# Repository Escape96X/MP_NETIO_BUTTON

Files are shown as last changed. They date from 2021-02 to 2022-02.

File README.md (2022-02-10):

# Manual
## How to install on esp8266 with Netio ESP flasher
Best method is to use Visual studio code with plugin Platformio.  
1. Download 'Kód' folder of this repository
2. After installation of VS code and Platformio override esptool.py in platformio
	- Windows path: C:\Users\\**username**\\.platformio\packages\tool-esptoolpy\esptool.py
3. Connect
	- Rx to Tx
	- Tx to Rx
	- GND to GND
	- PROG to PIO0
	- <a href = 'https://github.com/jiricmi/MP_NETIO_BUTTON/issues/14#issuecomment-888953459'>3,3 V to 3,3 V (You have to solder that to R2)</a>
	- <a href = 'https://github.com/jiricmi/MP_NETIO_BUTTON/issues/14#issuecomment-888953459'>RST to ESPEN (solder to RST button)</a>
4. Upload with platformio

<h2>NETIO button tutorial</h2>
<h3>How to set it up</h3>
<ol>
<li>Turn it on with ON/OFF switch</li>
<li>Hold both buttons until red light blinks once.</li>
<li>Open WiFi manager and find <b>NETIO-BUTTON</b> network and search <b>192.168.4.1</b> in internet browser</li>
<li>Under WiFis find your WiFi and click on it after that enter your password</li>
<li>After connecting, copy IP address of the device, reconnect to your network and enter new IP to your browser</li>
</ol>
<h3>Connect to Netio socket</h3>
<ol>
<li>Select <b>Action list</b> on main screen</li>
<li>Click on button <b>add</b></li>
<li>Enter IP adress of Netio socket (only IP without http:// or /netio.json)</li>
<li>Enter JSON string</li>
<li>Choose which button should use this command and submit</li>
<li> You can delete each record in table by clicking on button <b>Delete</b>
<li> On main screen click on button <b>Deep sleep</b> to end <b>conf-mode</b>
</ol>

<h2>Basic info</h2>
<p>
This is prototype of NETIO button that allow you to control the NETIO socket.
It works on sending HTTP request method.
On the other side, this communication is handled by the socket via JSON API. Button is made with small consumption. Button is only up when user sends HTTP request or turns on conf-mode.
</p>
<h3>Device structure</h3>
<p>
Device has 2 buttons with S1 and S2 marks. They are used for <b>JSON configure</b>.
User can program those buttons via conf-mode. <br>
</p>
<h3>LED and buzzer signaling</h3>
<p>
Device has LED with green and red color.
Buzzer is connected with red color of LED.<br>
If <b>green light</b> is on, device is trying to connect to wlan or communicate with the socket. <br>
If <b>red light</b> blinks once for longer time, device entered or quited conf-mode.<br> 
If <b>red light</b> blinks 2x with buzzer signalization, connection to wlan failed. <br>
If <b>red light</b> blinks 3x with buzzer signalization, HTTP communication failed.
Probably IP address of the socket is invalid. <br>
If <b>red light</b> blinks 4x with buzzer signalization, device wasn't able to recognize input. Please hold the button little bit longer.
</p>
<h2>Conf-mode</h2>
<p>
For entering conf-mode, hold both buttons until light turn on for 400ms. After that connect to AP called <b>NETIO-BUTTON</b>. Open browser and search <b>192.168.4.1</b>.
</p>
<h3>WiFi selection</h3>
<p>
On main screen, user is able to connect device to any close-range network without security or with WES, WPA or WPA2-personal. For update WiFi list, click on <b>Scan</b> button. <br>
By clicking on button with your wanted network, you will be transfer to security page (only if network is secured). If password is checked, page will show you IP address of device selected by DHCP server in network. And now you are able to connect to conf-mode via your network and appropriate IP address.
</p>
<h3>IP address of the socket</h3>
<p>
User is able to set 10 IP addresses for each button. So one HTTP request will be send a maximum of 10 devices at once. You can add IP address via form where you also select with button should use this IP address. It is possible to delete each address.
</p>
<h3>JSON message</h3>
<p>
Behind button configure you can find feature to write JSON message to JSON API of socket. Current JSON is below the form.
</p>
<h3>Disable conf-mode button</h3>
<p>This button will put device to sleep. Holding both buttons during conf-mode has same effect.</p>
<h3>Factory reset button</h3>
<p>Deletes whole EEPROM.</p>

# Obsah
📦MP_NETIO_BUTTON  
 ┣ 📂kod - - **Finální program**  
 ┣ 📂dokumentace - **Dokumentace s latex soubory**  
 ┃ ┗ 📜document.pdf   
 ┣ 📂mereni - **Waveform a screenshoty**    
 ┃ ┣ 📂esp32  
 ┃ ┃ ┣ 📂operace  
 ┃ ┃ ┣ 📂ustalene_stavy  
 ┃ ┃ ┗ 📜vysledky_mereni_esp32.xlsx  
 ┃ ┗ 📂esp8266  
 ┃ ┃ ┣ 📂operace  
 ┃ ┃ ┣ 📂ustalene_stavy  
 ┃ ┃ ┗ 📜vysledky_mereni_esp8266.xlsx  
 ┣ 📂navrh_vzorku - **Eagle**    
 ┃ ┣ 📂esp32  
 ┃ ┗ 📂esp8266  
 ┣ 📜.gitignore  
 ┗ 📜README.md  
# Poděkování
*Chtěl bych poděkovat panu učiteli Ing. Břetislavu Bakalovi za odborné vedení práce
a cenné rady, které mi pomohly tuto práci zkompletovat. Rád bych také poděkoval technickému řediteli Ing. Břetislavu Bakalovi ml. společnosti NETIO products a.s. za cenné
rady, věcné připomínky a vstřícnost při konzultacích a vypracování maturitní práce*.
# Úvod maturitní práce
V této maturitní práci porovnám platformy ESP8266 a ESP32 z hlediska spotřeby a reakčního času v takových podmínkách, aby bylo možné určit platformu, která je vhodnější pro funkční vzorek ovladače zásuvek od společnosti NETIO Products a. s. Jelikož je cílem vytvořit co nejvíce úsporné zařízení, jak je jen možné, budu porovnávat jednotlivé ustálené stavy. Zařízení také musí být uživatelsky přívětivé, tzn. není ideální, když
uživatel musí čekat na reakci několik sekund.

Dále na každé platformě porovnám rychlost a spotřebu připojení k WiFi síti a následné odeslání HTTP requestu.
Po vybrání vhodné metody ustáleného stavu, vytvořím konfigurační rozhraní pro editaci nastavení sítě a HTTP requestu, do kterého se bude přistupovat přes access point zařízení ESP.  

Ve finále vytvořím dva funkční koncepty ovladačů pro každou platformu. Tento koncept
bude vycházet z předchozího měření a zjištění. Funkčním vzorkem bude možné ovládat,
buď dvě různé zásuvky, nebo jednu zásuvku z dvěma výstupy. V závěru práce zhodnotím,
zda je možné vytvořit plnohodnotný produkt, či nikoliv.

# Zadání maturitní práce

- V dokumentaci popište technologie NETIO, ESP8266 a ESP32 s ohledem na požadované funkce ovladače
- Navrhněte vhodné uživatelsky přívětivé rozhraní pro konfiguraci ovladače a jeho
připojení do WiFi sítě
- Realizujte požadované funkce na ovladač:
	- vstup na 2 nezávislá tlačítka pro standardní dvojitý přepínač/spínač dvou samostatných zásuvek jednoho zařízení NETIO, eliminace rychlých mačkání (nervózní uživatel)
	- nepodařený příkaz/přepnutí vypínače (nepodaří se odeslat příkaz http) je indikován bliknutím LED a pípnutím buzzeru. Kontroluje se odpověď http serveru (např. 200, 404 návratové hodnoty)
	- Zvolte vhodnou technologii výroby funkčních vzorků (nepájivé pole, DPS) a vyrobte jeden funkční vzorek na bázi ESP8266 a druhý na bázi ESP32 s možností měření odebíraného proudu
	- Určete vhodnou metodu měření dynamické spotřeby energie v čase (reakční doby) pro různé režimy připojení, způsobu komunikace a platformy procesoru:
		- ESP je vypnuto a vzbudí se nějakým externím obvodem přes enable/reset vstup po stisku tlačítka
		- ESP je v deep sleep módu - low power režimu a vzbudí se tlačítkem
 		- ESP je kontinuálně zapnuto
		- Kolik energie spotřebují uvedené režimy při napájení z baterie. Výsledky měření názorně porovnejte
	- Celou dokumentaci včetně výpisů zdrojového programu s komentářem veďte ve verzovacím systému Git a elektronicky doložte k tištěné podobě dokumentace
## Kritéria funkčnosti
- vyrobené vzorky ovladače (ESP8266 a ESP32) jsou funkční
- je vytvořeno uživatelské rozhraní pro konfiguraci ovladač
- bylo provedeno měření spotřeby a doby odezvy pro oba typy ovladače

## Výstupy
- srovnání platforem ESP32 a ESP8266 s ohledem na požadované funkce
- návrh požadovaných funkcí ovladače
- návrh variant ovladače s platformou ESP32 a ESP8266 ve formě ověření konceptu
- zdrojové kódy v repozitáři GIT (GitHub nebo GitLab)
- schéma zapojeni všech zkoušených variant v řešení
- srovnání spotřeby a reakční doby funkčních vzorků

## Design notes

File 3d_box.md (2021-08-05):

# 3D prited box
this box is supporting SMD in this repository. 

Box is [HERE](https://a360.co/3rSHOem). Password is "netio-button".

Box is printed on PRUSA MK3S nozzle 0.4 with PETG filament

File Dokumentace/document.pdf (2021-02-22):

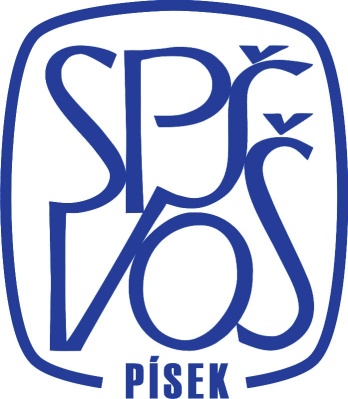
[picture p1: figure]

Střední průmyslová škola a Vyšší odborná škola, Písek, Karla Čapka 402, Písek

18-20-M/01 Informační technologie

# Maturitní práce

# Dálkové ovládání zásuvek NETIO

Téma číslo 12

autor:

Milan Jiříček, B4.I

vedoucí maturitní práce:

Ing. Břetislav Bakala

Písek 2020/2021

## Anotace

Maturitní práce se zaměřuje na porovnání platforem ESP8266 a ESP32. Cílem je vytvořit

ovladač pro ovládání zásuvek značky NETIO s webovou aplikací pro konfiguraci a zjistit,

která platforma je vhodná pro realizaci funkčního vzorku z hlediska spotřeby energie

a reakční doby.

## Annotation

The graduation thesis focuses on the comparison of the ESP8266 and ESP32 platforms.

The goal is to create a driver for controlling NETIO sockets with a web application

for configuration and to find out which platform is suitable for the implementation of

a functional sample in terms of energy consumption and response time.

Poděkování

Chtěl bych poděkovat panu učiteli Ing. Břetislavu Bakalovi za odborné vedení práce

a cenné rady, které mi pomohly tuto práci zkompletovat. Rád bych také poděkoval technic-

kému řediteli Ing. Břetislavu Bakalovi ml. společnosti NETIO products a.s. za cenné rady,

věcné připomínky a vstřícnost při konzultacích a vypracování maturitní práce. V neposlední řadě chci poděkovat Mgr. Haně Maříkové a Mgr. Vladimíře Špirhanzlové za pomoc

při gramatické a stylistické kontrole.

# Obsah

1 Úvod | 5
2 Teoretický úvod do problematiky | 6
3 Metodika postupu | 11
4 Měření spotřeby a času | 16

5 Vytvoření funkčních vzorků | 24
6 Závěr | 25
Přílohy | 27
A Příloha | 28

# Kapitola 1

# Úvod

# Kapitola 2

# Teoretický úvod do problematiky

## 2.1 Zásuvka NETIO

## 2.2 Platforma ESP

ESP jsou rodina mikročipů od společnosti Espressif Systems.

### 2.2.1 ESP8266

Historie

ESP8266 je levný mikročip, který umí využívat WiFi. První chip, který se dostal na světlo

světa byl v modulu ESP-01. Tento modul dokázal připojit se na WiFi síť a provádět

jednoduché TCP/IP spojení. Získal si velkou oblibu díky nízké ceně. Jsou vhodné pro IoT

jako například automatizace, zabezpečení, chytré domy atd.

Specifikace

Pro tuto maturitní práci bude použit modul WT8266-S1, který je vytvořen společností

Wireless-Tag, protože tento modul je používán ve společnosti NETIO products a. s. Je

založen na mikročipu ESP8266.

ESP8266 integruje vylepšenou verzi procesoru L106 Diamond series 32-bit vytvořený

firmou Tensilica s podporou frekvencí 80 MHz a 160 MHz a RTOS¹
. K dispozici je 36 KB

RAM a 16 Mbit Flash paměti. Intergrovaný v systému je také 10 bitový analog-digitální

převodník. Modul podporuje standard IEEE802.11 b/g/n 2 a sadu protokolů TCP/IP.

1Operační systém v realném čase
2Standard pro lokální bezdrátové sítě

WiFi 2,4 GHz umožňuje WPA/WPA2 3 , rychlost až 72,2 Mbps a ke komunikaci využívá

anténu PCB. Zařízení má 16 GPIO pinů⁴
(viz. obr. 2.1) z toho jsou některé piny využívány

na specifické činnosti. Např. pokud při bootu ESP8266 přivedeme GROUND na GPIO

0, zařízení se přepne do UART⁵ módu a je možné nahrát do flash paměti program. Další

informace jsou na obrázku 2.2.

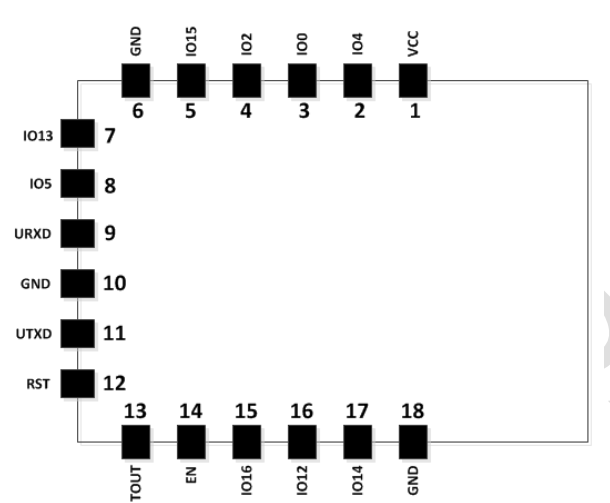
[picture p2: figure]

Obrázek 2.1: ESP8266 pinout: Literatura [1]

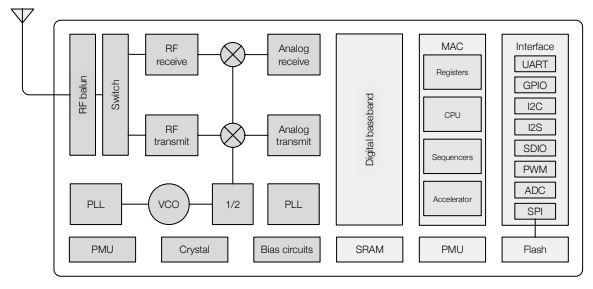
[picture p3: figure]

Obrázek 2.2: ESP8266 blokový diagram funkcí: Literatura [2]

### 2.2.2 ESP32

ESP32 je mladší model z řady ESP, který byl vydán v roce 2016. Tento mikročip má

integrované WiFi i Bluetooth. Série ESP32 obsahuje mikroprocesor Tensilica Xtensa LX6

3Chráněný přístup k WiFi
4Vstupně výstupní pin
5Univerzální asynchronní přijmač, vysílač v dvou jádrové či jednojádrové verzi, který může operovat na 160 MHz nebo 240 MHz.

SRAM je zde byla zvetšena na 520 kB. WiFi může dosáhnout rychlosti až 150 Mbps

společně se zabezpečením WPA/WPA2. Kromě IPv4 je možnost použít i IPv6. ESP32

integruje 12 bitový analog-digitální převodník. Oproti ESP8266 je do tohoto modelu za-

budován senzor teploty. ESP32 disponuje 36 GPIO piny. Další funkce jsou na obrázku 2.3.

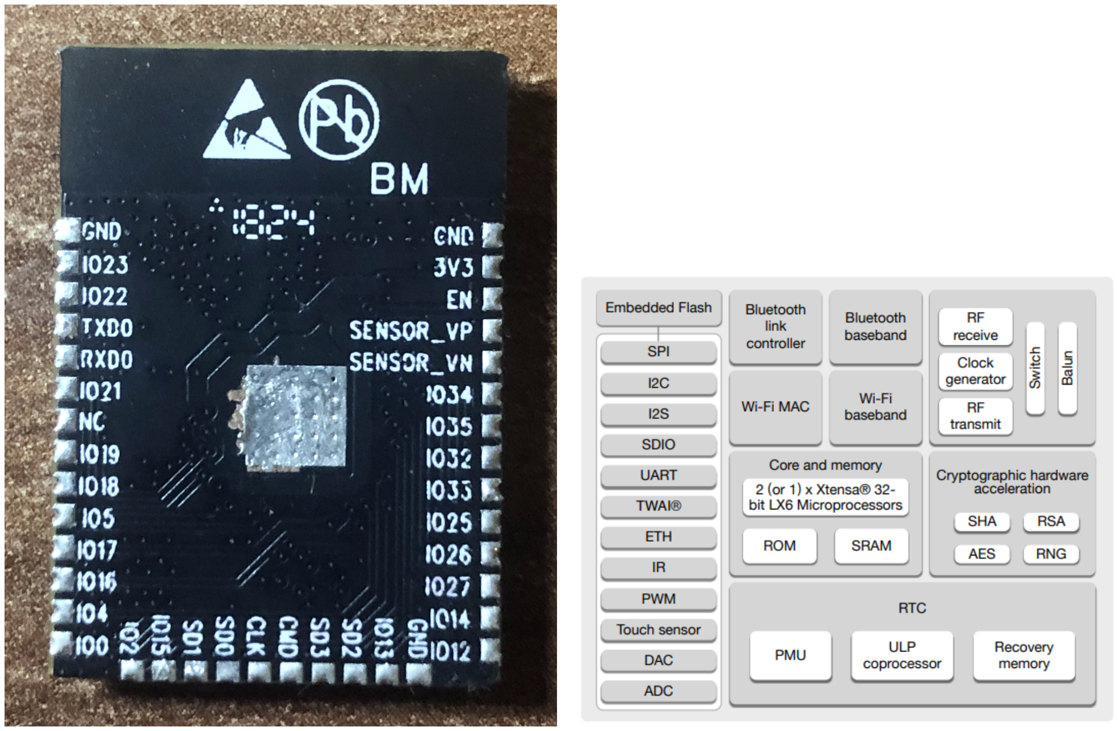
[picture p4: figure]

(a) pinout | (b) blokový diagram: Literatura [3]

Obrázek 2.3: ESP32 pinout a blokový diagram

### 2.2.3 Deep sleep

Platforma ESP lze také uvést do úsporného režimu. Jednoduše to znamená vypnutí ne-

důležitých částí pro ustálený stav. ESP8266 celkově nabízí 3 druhy úsporných režimů.

Modem, light a deep. Pro moji maturitní práci použiji deep sleep, který je nejúsporněj-

ších. Kromě RTC⁶
se vše vypne, včetně CPU či WiFi. V tomto režimu je také možné

uchovat data v tzv. RTC paměti, která jsou dostupná i po obnovení. Průměrná spotřeba

je 20 µA a je vhodný pro jakýkoliv projekt na akumulátor či baterii.

Probuzení ESP8266 probíhá, buď po nastaveném čase, kde je nutné připojit pin GPIO

6Hodiny realného času

### 16 tzv. wake-up pin na RESET (viz. obr. 2.4a), ten po uplynutí nastaveného času se na

krátkou dobu přepne z log. 1 na log. 0 a vyresetuje ESP8266, a nebo můžeme na RESET

přivést krátce tlačítkem logickou nulu a obnovíme ESP hardwarově (viz. obr. 2.4b).

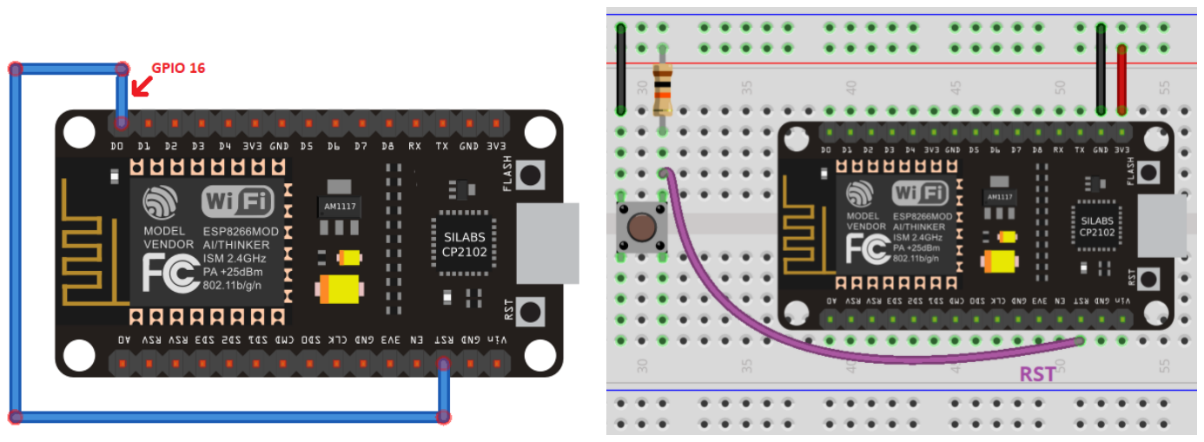
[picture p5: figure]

(a) Sotwarově po daném čase | (b) Hardwarově

Obrázek 2.4: ESP8266 probuzení z deep sleep po daném čase: Literatura [4]

Jelikož ESP32 je novější model, deep sleep se liší v používání. ESP32 neprobouzíme přes

RESET pin protože se ani na mikročipu ani nenachází. Pokud chceme ESP probudit po

určitém čase, nastavíme to pouze v programu a nemusíme žádné piny propojovat. V situ-

aci hardwarového probuzení je nutné definovat pin probuzení a při jaké logické hodnotě

se má probudit. Tento pin musí být tzv. RTC_GPIO⁷

## 2.3 LDLN030

LDLN030 je napěťový regulátor, který pracuje se vstupním napětím od 1,6 V do 5,5 V.

Výstupní napětí dokáže stabilizovat na 3,3 V a pokud napětí klesne pod 3 V, odpojí

zařízení napojené na výstupu. Tato součástka má časté použití v mobilních telefonech,

HDD a SSD discích a ostatních rařízeních napájené baterií.

Regulátor má celkem 5 pinů, a to vstup, výstup, GROUND, enable pin a Power Good.

Enable pin rozhoduje zda součástka funguje či nikoliv, pokud je přivedena na zem, výstup

je 0 V. Power Good je pin, který může informovat například základní desku během POST⁸ ,

že napájení je v pořádku a může pokračovat v činnosti.

7Pin, který je v činnosti i během spánku ESP
8Power On Self Test

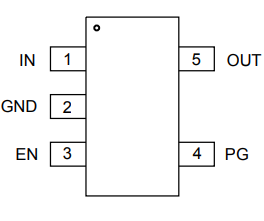
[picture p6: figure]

Obrázek 2.5: LDLN030 Pinout: Literatura [5]

# Kapitola 3

# Metodika postupu

## 3.1 Tvorba měřecího vzorku

Pro měření jednotlivých scénářů jsem si vytvořil vzorek, který byl určen pouze na měření.

Cílem bylo vytvořit vzorek jednoduše modifikovatelný, proto jsem zvolil pájivé pole na

základní část.

Na pájivém poli jsem napájel testovanou ESP platformu společně s přívodem, který byl

5 V. ESP má operační napětí 3,3 V, proto bylo nutné přidat stabilizator LDLN030,

který napětí stabilizoval na operačním napětí. Stabilizátor byl zapojen dle doporučeného

diagramu v datasheetu.

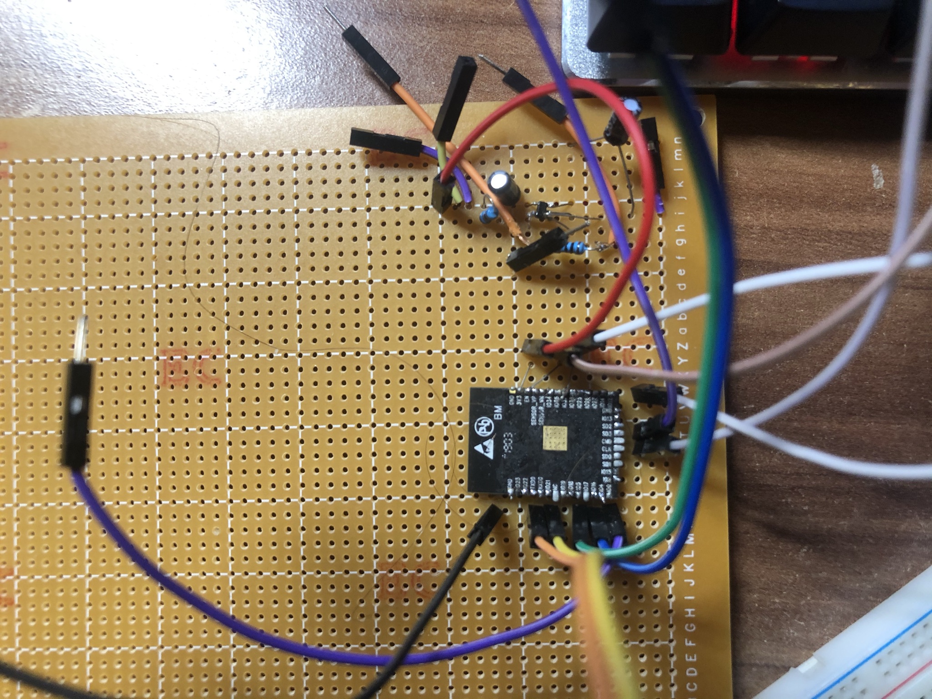
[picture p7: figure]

Obrázek 3.1: Vzorek pro měření na pajivém poli

Dále k potřebným GPIO pinům jsem napájel vodiče pro pozdější manipulaci. Pro další

specifická zapojení, jako např. tlačítko, jsem použil nepájivé pole, které jsem vždy připojil

specificky pro dané měření.

## 3.2 Měření připojení k WiFi a odeslání HTTP requestu

Cílem měření je zjistění rychlostí a spotřeby připojení různými způsoby k přístupo-

vému bodu a následné porovnání případů. Do měření je také započítáné odesílání HTTP requestu zásuvce. Jsou vytvořeny celkem 4 případy akcí:

- statická IP adresa - Zařízení dostane IP adresu, masku a bránu staticky sta-

ticky nakonfigurovanou. Na access pointu bude vyplé DHCP a komunikace nebude

zabezpečena.

- dynamická IP adresa - Bude využit DHCP protokol, kde zařízení požádá DHCP

server o IP adresu, kterou mu access point přidělí společně s bránou, maskou a s ča-

sem, kdy tato adresa platí. Při měření nebude přístupový bod zabezpečen.

- Zabezpečené připojení - Připojení na access point bude šifrované pomocí WPA2 -

PSK. DHCP server bude zapnut. Toto je simulace klasického uživatelského použí-

vání.

- Odeslání HTTP requestu - Zařízení je připojené k WiFi. Odešle zprávu zásuvce

a pokud dostane zpětnou vazbu od zásuvky, ukončí se činnost.

Ve všech scénářích bude měřeno zařízením ANALOG DISCOVERY 2 od Digilent.

Frekvence procesoru je 160 MHz a AP je vzdálen 3,5 m od zásuvky a funkčního vzorku

ovladače.

### 3.2.1 Spotřeba

Měřen bude úbytek napětí na bočníku¹ o velikosti určené u měření. V programu k mě-

řícímu zařízení je možné stejně jako na osciloskopu vytvořit graf naměřených hodnot v

dané vzorkovací frekvenci. Hodnoty napětí bude převedeno na hodnoty el. proudu pomocí

Ohmova zákona I =

U
R

. Amplitudy el. proudu budou sečteny a vyděleny počtem vzorků

[DOPLNIT VZOREC]. Tato operace nám poskytne zjištění průměrného el. proudu ve

scénáři. Spotřebu již vypočítáme dle:

E = U × I ×

t
3600

Čas t v sekundách je možné zjistit v následující kapitole.

1nízkoohmový rezistor

### 3.2.2 Reakční čas

Z naměřeného případu bude vyjmuta klidová část a rozdíl mezi posledním a prvním

vzorkem je poté reakční čas. V případě HTTP requestu nebude počítána část konfigurace

WiFi. Společně s měřením byl na serial monitor odesílány zprávy, kde se program

nachází. Poté se vyjmula část, která dle serial monitoru nepatří do scénáře.

## 3.3 Ustálené stavy

Pro ustálené stavy byly navrhnuty jednoduché programy pro co nejlepší porovnání. Ustá-

lený stav je stav, kdy zařízení čeká na uživatelský podnět jako např. stisknutí tlačítka.

Ideální ustálený stav musí splňovat:

1. nejkratší možnou reační dobu
2. nejnižší možnou spotřebu pro co nejdelší výdrž baterií

Reakční doba musí být v rámci uživatelské přívětivosti tzn. probuzení z tohoto stavu

nesmí trvat více jak 1,5 s. Zároveň se zařízení nesmí vypnout zdůvodu vybité baterie za

krátkou dobu. Porovnání proběhne mezi třemi scénáři, které mají jiné vlastnosti. Vybrány

byly následující:

- Kontinuální režim - V tomto stanu není žádná funkce ESP vypnuta.
- Deep sleep - ESP vypne vše až na RTC (kapitola viz. 2.2.3 na straně 8).
- Enable button - ESP je vypnuto pomocí přivedené GROUND na pin ENABLE.

### 3.3.1 Spotřeba

Cílem měření je nalézt stav s nejmenší spotřebou energie, jelikož finální prvek bude na-

pájen z baterií je důležité co nejdelší výdrž. Programy, které byly napsány pro měření:

- Kontinuální režim - Zařízení má nastavený určitý GPIO na tlačítko a monitoruje

zda bylo zmáčknuto. ESP také má otevřenou sériovou komunikaci.

- Deep sleep - Program zajišťuje probuzení ESP každých 5 s a odesílání zprávy na

serial monitoring.

- Enable button - Pro měření této situace není třeba specifický program

Pro měření bude použit ANALOG DISCOVERY s jeho funkcí osciloskopu. Na napá-

jení bude přidán bočník o velikosti 0,7 Ω, 10,5 Ω nebo 4,7 Ω

2
. Pomocí Ohmova zákona

I =

U
R

je možné zjistit el. proud. Příkon, který bude porovnán vypočítáme dle vztahu:

P = U × I

OBRÁZKY ZAPOJENÍ

### 3.3.2 Probuzení z ustálených časů

Ovladač, který je již připojen k WiFi, po stisknutí tlačítka odešle HTTP request zásuvce,

která zareaguje přepnutím stavu a odesláním zprávy zpět ovladači zda se povedlo či

nikoliv.

Reakční doba byla změřena pomocí kamery. K tlačítku jsem připojil LED, místnost jsem

izoloval od světla a zmáčknutí tlačítka a reakci zásuvky jsem natočil ve zpomaleném

režimu s 240 snímky za sekundu. Pro upravení videa jsem použil trial verzi programu

Sony Vegas (viz. obr. 3.2). Našel jsem rozsvícení LED tlačítka a rozsvícení LED zásuvky

ve videu a ustřihl jsem tento úsek od zbytku videa. Program poskytuje zobrazení počtu

snímku daného úseku. Reakční čas je následovně možný zjistit pomocí:

t =

Počet snímků úseku
Počet snímků za sekundu

2Je nutné zvolit takový odpor, aby byl úbytek napětí měřitelný.

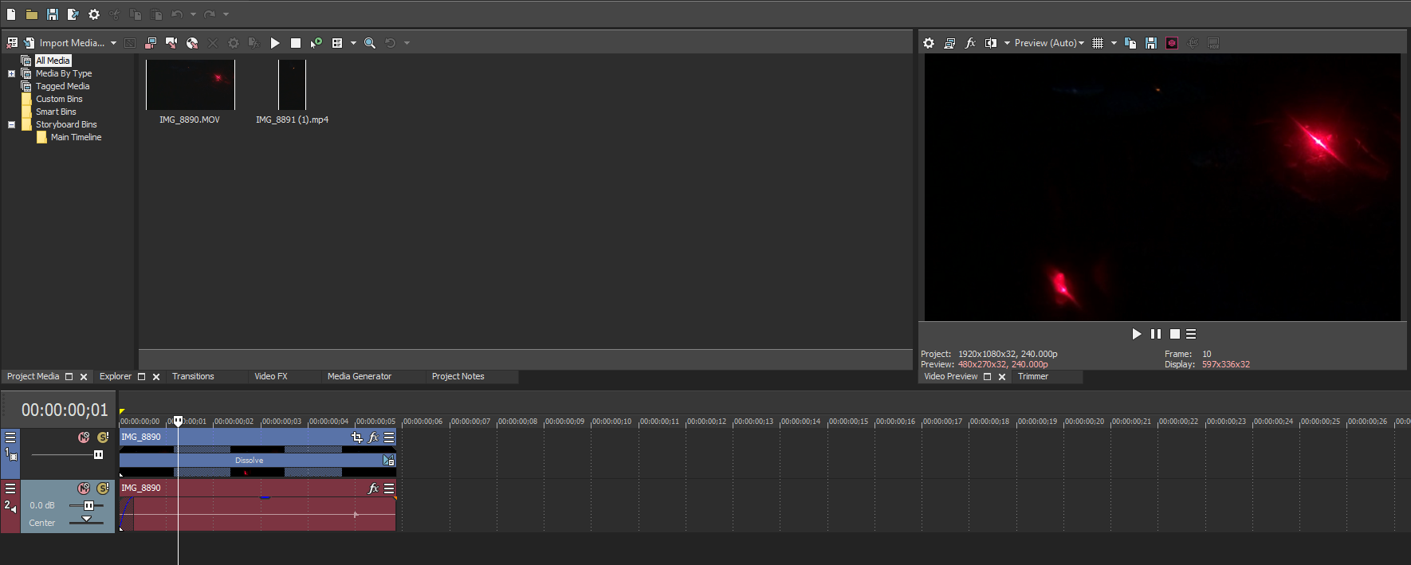
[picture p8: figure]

Obrázek 3.2: Ukázka postupu pro měření reakčních časů

# Kapitola 4

# Měření spotřeby a času

Všechny výpočty jsou k nalezení v adresáři "Měření"v souborech excel společně s použi-

tými programy a naměřenými hodnotami v grafech.

## 4.1 ESP8266

### 4.1.1 Spotřeba a reakční doba ustálených stavů

Spotřeba

Spotřeba jednotlivých scénářů je měřena dle metodiky 3.3.1 na straně 13. Bočník pro

měření úbytku napětí byl o velikosti 4,7 Ω.

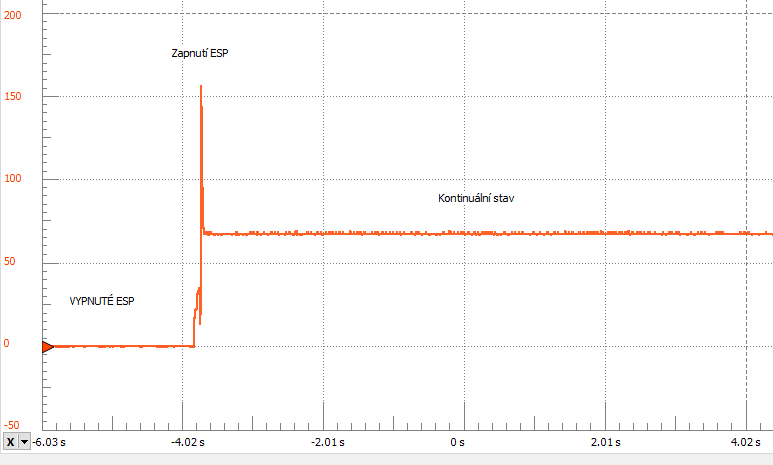
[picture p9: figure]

Obrázek 4.1: ESP8266 graf kontinuálního ustáleného stavu

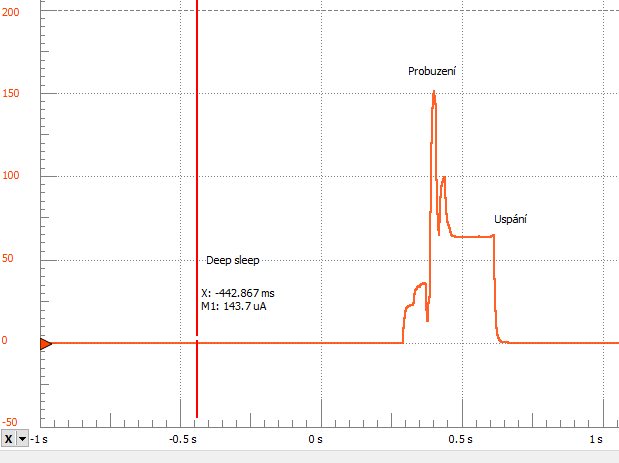
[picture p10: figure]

Obrázek 4.2: ESP8266 graf deep sleep ustáleného stavu

Situace enable button nebyla možná změřit zařízením ANALOG DISCOVERY 2

ani na bočníku o velikosti 0,7 Ω kvůli velice nízkému úbytku napětí, který se v datasheetu

WT8266 pohybuje v jednotkách µA. V tomto případě pro výpočty je použita hodnota,

kterou určil výrobce v datasheetu.

Tabulka 4.1: ESP8266 porovnání spotřeby ustálených stavů

Ustálený stav | U(V ) I(A) P(W)
Kontinuální Deep sleep Enable button | 3, 3 67, 66 × 10⁻³ 223, 3 × 10⁻³ 3, 3 138, 20 × 10⁻⁶ 460, 0 × 10⁻⁶ 3, 3 3, 00 × 10⁻⁶ 9, 9 × 10⁻⁶

Dle tabulky 4.1 je možné vidět jednotlivé situace. Největším příkonem disponuje konti-

nuální ustálený stav z důvodu běžícího programu na kontrolu interakce. Nejmenší spotřeba

je naopak vypnuté ESP přes enable pin.

Tabulka 4.2: ESP8266 porovnání reakčního času ustálených stavů

Ustálený stav | t(ms)
Kontinuální Deep sleep Enable button | 196 983 3 208

Reakční čas

Reakční čas byl měřen dle metodiky 3.3.2 na straně 14. Nejrychlejší ustálený stav je

kontinuální, kvůli připravenosti na interakci viz. tabulka 4.3. Nejdéle trvá vypnuté ESP,

protože je nutné ESP zapnout, nastavit konfiguraci a připojit na WiFi, zatím co zapnuté

ESP je již připraveno.

Porovnání

Pro porovnání spotřeb budeme předpokládat, že zařízení je napájeno 3× NiZn akumulá-

torem typu AA, které společně mají kapacitu 3750 mAh, což je možné prevést na energii

vztahem E = Uaku × kapacita. a dále vztahem¹
tp =

Ebat
P

zjistit provozní čas (viz. tabulka

4.3). Zařízení není schopno dosáhnout této výdrže protože pokud napětí klesne pod 3 V,

stabilizátor napájení odpojí.

Tabulka 4.3: ESP8266 porovnání ustálených stavů

Ustálený stav | P[W] tp[h] t[ms]
Kontinuální Deep sleep Enable button | 223, 3 × 10⁻³ 75,6 196 460, 0 × 10⁻⁶ 36 993,1 983 9, 9 × 10⁻⁶ 1 704 545,0 3 208

Kontinuální stav, zatímco má výdrž v rámci několika dní, reakční čas trvá necelých

200 ms. Enable button situace naprosto opačná. Reakční čas je pro uživatele dlouhý, ale

výdrž v tomto stavu bez interakce by se pohybovala v letech. Dobrý kompromis je situace

deep sleep, kdy zařízení reagovalo vždy do jedné sekundy a teoretická výdrž je v jednot-

kách let.

1
tp - provoz v ustáleném režimu, Ebat - energie 3× AA akumulátorů

### 4.1.2 Připojení k WiFi a odeslání HTTP requestu

Měření proběhlo dle metodiky 3.2 na straně 11 na bočníku 0,7 Ω.

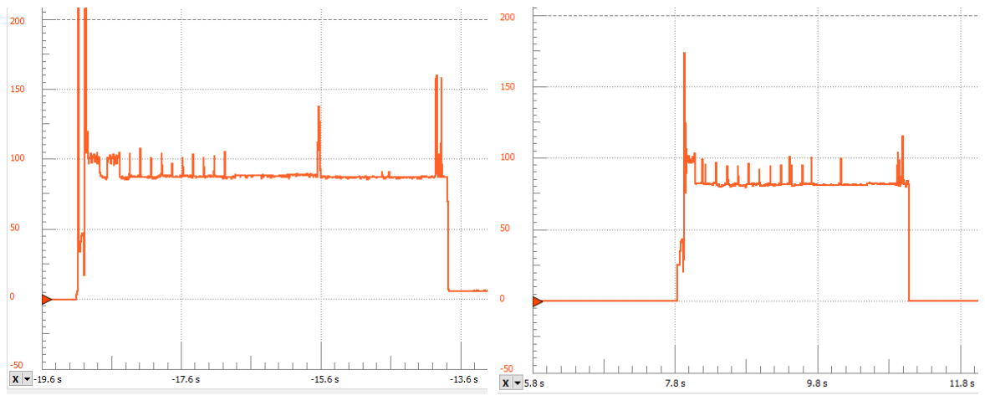
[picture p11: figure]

(a) Dynamická IP | (b) Statická IP

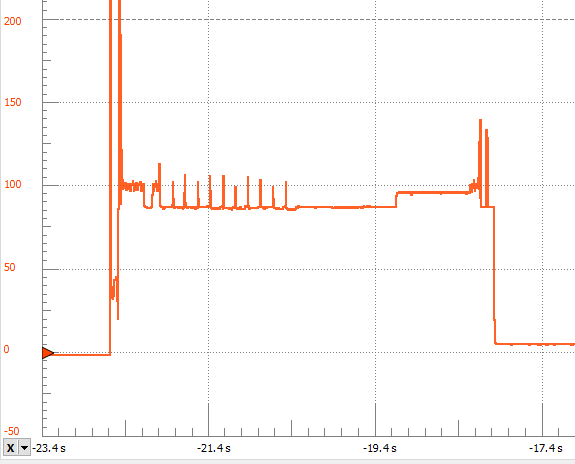
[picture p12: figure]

(c) Zabezpečené, dynamická IP

Obrázek 4.3: ESP8266 grafy WiFi situací

Z tabulky 4.7 je možné vidět, že příkon P je téměř totožný v každé operaci. Nej-

větší rozdíl, který ovlivňuje spotřebu, je čas, za který se úkon vykoná. Jelikož připojení

pomocí statické IP adresy trvalo nejkratší dobu, má také nejmenší spotřebu ener-

gie. Samotná komunikace HTTP má nejnižší spotřebu ze všech definovaných operací a

jeden cyklus operace spotřebuje zanedbatelné množství energie.

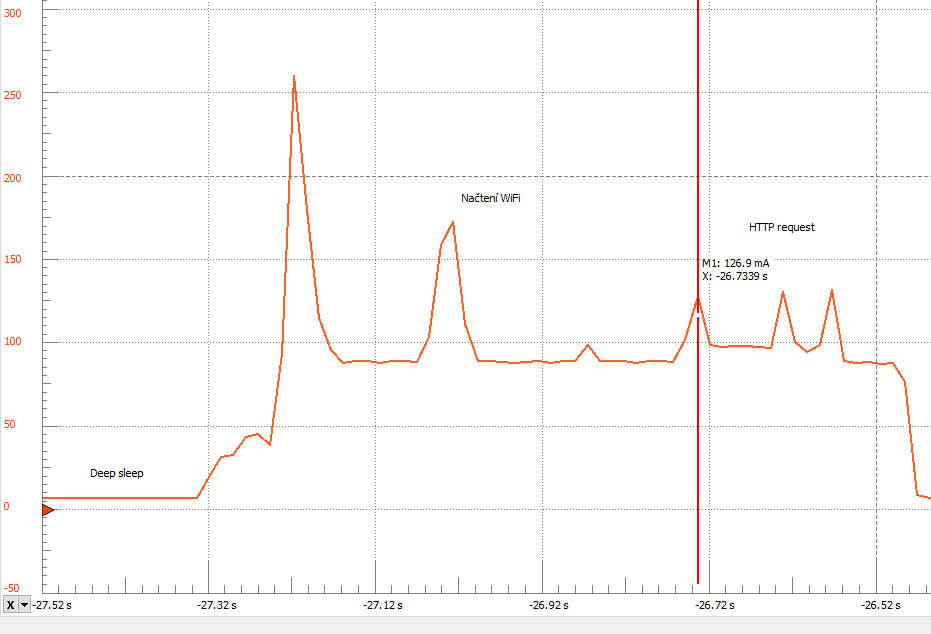
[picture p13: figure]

Obrázek 4.4: ESP8266 graf HTTP requestu

Tabulka 4.4: ESP8266 Spotřeba operací

Operace | U(V) I[mA] t[ms] P[mW] | E[µW h]
Dynamické připojení Statické připojení Zabezpečené připojení HTTP komunikace | 3,3 89,5 5 300 295 3,3 83,0 3 143 274 3,3 90,9 4 606 300 3,3 76,7 483 253 | 435 239 383 34

## 4.2 ESP32

### 4.2.1 Spotřeba a reakční doba ustálených stavů

Spotřeba

Spotřeba jednotlivých scénářů je měřena dle metodiky 3.3.1 na straně 13. Bočník pro

měření úbytku napětí byl o velikosti 10,5 Ω.

Ustálený stav enable pin nebyl naměřen zařízením Analog Discovery 2 z důvodu velmi

nízkému úbytku napětí na bočníku. K porovnání bude použita hodnota z datasheetu.

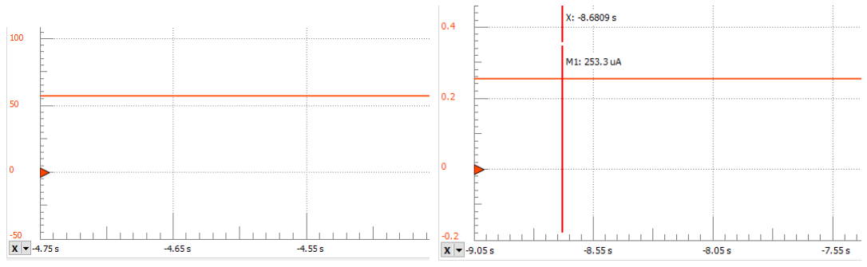
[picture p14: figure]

(a) Kontinuální | (b) Deep sleep

Obrázek 4.5: ESP32 grafy ustálených stavů

Tabulka 4.5: ESP32 porovnání spotřeby ustálených stavů

Ustálený stav | U[V ] I[A] P[W]
Kontinuální Deep sleep Enable button | 3, 3 57, 39 × 10⁻³ 189, 4 × 10⁻³ 3, 3 253, 39 × 10⁻⁶ 838, 0 × 10⁻⁶ 3, 3 1, 00 × 10⁻⁶ 3, 3 × 10⁻⁶

Reakční čas

Získání reakčních časů jednotlivých možností zapojení ESP32 proběhlo způsobem dle 3.3.1

na straně 13. Tabulka 4.6 ukazuje, že nejdéle trval ustálený režim v podobě vypnutého

ESP32 přes enable pin a nejkratší dobu trval kontinuální ustálený stav. Kompromis mezi

těmito dvěma stavy byl deep sleep ustálený stav, který se pohyboval okolo sekundy.

Tabulka 4.6: ESP32 porovnání reakčního času jednotlivých situací

Ustálený stav | t[ms]
Kontinuální Enable button Deep sleep | 188 2 333 1 071

### 4.2.2 Připojení k WiFi a odeslání HTTP requestu

Měření proběhlo podle metodiky 3.2 na straně 11.

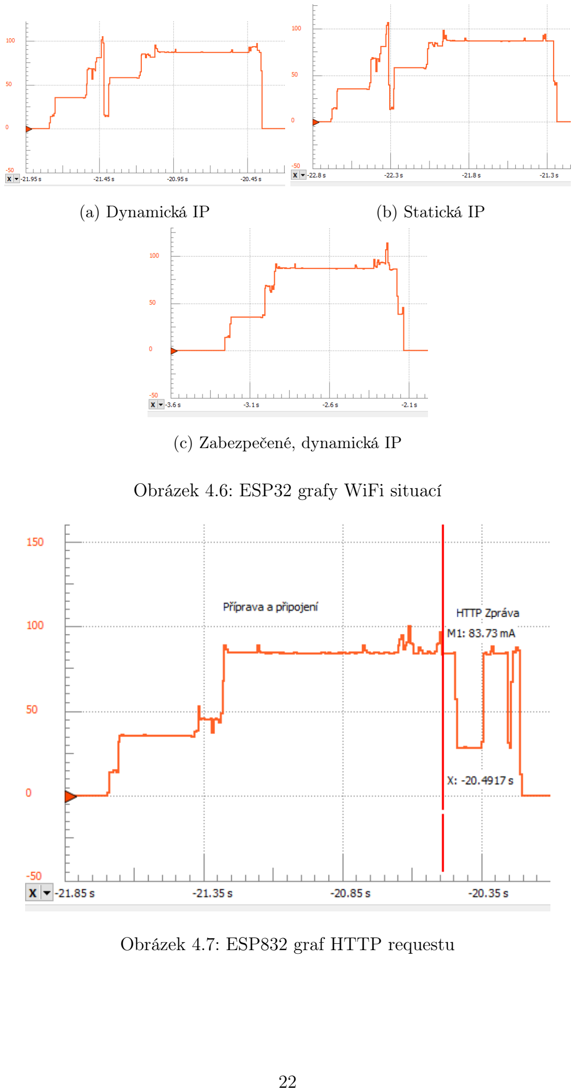
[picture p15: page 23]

(a) Dynamická IP | (b) Statická IP
(c) Zabezpečené, dynamická IP

Obrázek 4.6: ESP32 grafy WiFi situací

Obrázek 4.7: ESP832 graf HTTP requestu

Tabulka 4.7: ESP8266 Spotřeba operací

Operace | U[V] I[mA] t[ms] P[mW] | E[µW h]
Dynamické připojení Statické připojení Zabezpečené připojení HTTP komunikace | 3,3 72,0 1 406 238 3,3 69,2 1 400 228 3,3 74,7 1 081 246 3,3 62,6 281 207 | 92 88 74 16

## 4.3 Porovnání získaných výsledků

### 4.3.1 Ustálené stavy

Z tabulky 4.8 je možné vidět jak si platformy vedly proti sobě.

Pokud ovladač neustále běží s připojenou WiFi čas reakce je velmi rychlý a v obou případech uživatel nepostřehne prodlevu mezi aktivací ovladače a sepnutí relé v zásuvce. Časy

mezi platformami se liší minimálně a rozdíl se pohybuje v rámci milisekund, přesto je

ESP32 lehce rychlejší.

Zapnutí vypnutého ESP, následné načtení a připojení k WiFi je nejdelší ze všech scénářů,

který trvá několik sekund. Pro uživatele je velice pomalé a v realném produktu dle mého

názoru zcela nepoužitelné. I přesto je ESP32 je mnohem rychlejší a to zhruba o 1 s.

Deep sleep je alternativa mezi kontinuálním a vypnutým stavem. ESP totiž vypne vetšinu

svých částí. Díky tomu je schopno relativně rychle zareagovat na budící signál. Reakce

obou ovladačů je cirka 1 s. Zde vede ESP8266, které je zhruba o 100 ms rychlejší. Je to

zdůvodu komplikovanější struktuře ESP32.

Tabulka 4.8: Porovnání reakčních časů ústálených stavů platforem

Ustálený stav | ESP8266 ESP32 [ms] [ms]
Kontinuální Enable Deep sleep | 196 188 3 208 2 333 983 1 071

# Kapitola 5

# Vytvoření funkčních vzorků

## 5.1 Tvorba uživatelského rozhraní

# Kapitola 6

# Závěr

# Seznam tabulek

4.1 ESP8266 porovnání spotřeby ustálených stavů | 17
4.2 ESP8266 porovnání reakčního času ustálených stavů | 18
4.3 ESP8266 porovnání ustálených stavů | 18
4.4 ESP8266 Spotřeba operací | 20
4.5 ESP32 porovnání spotřeby ustálených stavů | 21
4.6 ESP32 porovnání reakčního času jednotlivých situací | 21
4.7 ESP8266 Spotřeba operací | 23
4.8 Porovnání reakčních časů ústálených stavů platforem | 23

# Seznam obrázků

2.1 ESP8266 pinout: Literatura [1] | | 7
2.2 ESP8266 blokový diagram funkcí: Literatura [2] | | 7
2.3 ESP32 pinout a blokový diagram | | 8
2.4 ESP8266 probuzení z deep sleep po daném čase: Literatura [4] | | 9
2.5 LDLN030 Pinout: Literatura [5] | 10
3.1 Vzorek pro měření na pajivém poli | 11
3.2 Ukázka postupu pro měření reakčních časů | 15
4.1 ESP8266 graf kontinuálního ustáleného stavu | 16
4.2 ESP8266 graf deep sleep ustáleného stavu | 17
4.3 ESP8266 grafy WiFi situací | 19
4.4 ESP8266 graf HTTP requestu | 20
4.5 ESP32 grafy ustálených stavů | 21
4.6 ESP32 grafy WiFi situací | 22
4.7 ESP832 graf HTTP requestu | 22

# Příloha A

# Příloha

# Literatura

[1] WT8266. | Wireless-Tag | Technology | Co.,Limited | [Online]. | Ir-
vine | (C): | Wireless-Tag, | 2021 | [cit.2021–02–22]. | Dostupné | z:

https://www.tme.com/Document/12266bdd8a30eeb152305461b089a151/WT8266-

S1.pdf

[2] ESP8266. | Espressif | Systems | [Online]. | Shangai, | Čína:
Espressif | Systems, | 2020 | [cit.2021–02–22]. | Dostupné | z:

https://www.espressif.com/sites/default/files/documentation/0a-

esp8266ex_datasheet_en.pdf

[3] ESP32. | Espressif | Systems | [Online]. | Shangai, | Čína:
Espressif | Systems, | 2020 | [cit.2021–02–22]. | Dostupné | z:

https://www.espressif.com/sites/default/files/documentation/esp32_datasheet_en.pdf

[4] ESP8266 | deep | sleep. | Random Nerd Tutorials [Online]. | Porto, Por-
tugalsko: RandomNerdTutorials.com, 2019 | [cit.2021–02–22]. | Dostupné z:

https://randomnerdtutorials.com/esp8266-deep-sleep-with-arduino-ide/

[5] DHCP protokol. | In: Wikipedia: the free encyclopedia [Online]. | San Fran-
cisco (CA): Wikimedia Foundation, | 2021 | [cit.2021–02–22]. | Dostupné z:

https://en.wikipedia.org/wiki_Dynamic_Host_Configuration_Protocol

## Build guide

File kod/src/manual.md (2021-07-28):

<html>
<head>
<style>
        body {
            font-family: "Helvetica",serif;

        }
    )
</style>
</head>
<body>
<h1>NETIO button tutorial</h1>
<h2>How to set it up</h2>
<ol>
<li>Turn it on with ON/OFF switch</li>
<li>Hold both buttons until red light blinks once.</li>
<li>Open WiFi manager and find <b>NETIO-BUTTON</b> network and search <b>192.168.4.1</b> in internet browser</li>
<li>Under WiFis find your WiFi and click on it after that enter your password</li>
<li>After connecting, copy IP address of the device, reconnect to your network and enter new IP to your browser</li>
</ol>
<h2>Connect to Netio socket</h2>
<ol>
<li>Select <b>Devices</b> on main screen</li>
<li>Click on button <b>add</b></li>
<li>Enter IP adress of Netio socket (only IP without http:// or /netio.json)
<li>Enter JSON string</li>
<li>Choose which button should use this command and submit</li>
<li> You can delete each record in table by clicking on button <b>Delete</b>
<li> On main screen click on button <b>Deep sleep</b> to end <b>conf-mode</b>
</ol>

<h2>Basic info</h2>
<p>
This is prototype of NETIO button that allow you to control the NETIO socket.
It works on sending HTTP request method.
On the other side, this communication is handled by the socket via JSON API. Button is made with small consumption. Button is only up when user sends HTTP request or turns on conf-mode.
</p>
<h3>Device structure</h3>
<p>
Device has 2 buttons with S1 and S2 marks. They are used for <b>JSON configure</b>.
User can program those buttons via conf-mode. <br>
</p>
<h3>LED and buzzer signaling</h3>
<p>
Device has LED with green and red color.
Buzzer is connected with red color of LED.<br>
If <b>green light</b> is on, device is trying to connect to wlan or communicate with the socket. <br>
If <b>red light</b> blinks once for longer time, device entered or quited conf-mode.<br> 
If <b>red light</b> blinks 2x with buzzer signalization, connection to wlan failed. <br>
If <b>red light</b> blinks 3x with buzzer signalization, HTTP communication failed.
Probably IP address of the socket is invalid. <br>
If <b>red light</b> blinks 4x with buzzer signalization, device wasn't able to recognize input. Please hold the button little bit longer.
</p>
<h2>Conf-mode</h2>
<p>
For entering conf-mode, hold both buttons until light turn on for 400ms. After that connect to AP called <b>NETIO-BUTTON</b>. Open browser and search <b>192.168.4.1</b>.
</p>
<h3>WiFi selection</h3>
<p>
On main screen, user is able to connect device to any close-range network without security or with WES, WPA or WPA2-personal. For update WiFi list, click on <b>Scan</b> button. <br>
By clicking on button with your wanted network, you will be transfer to security page (only if network is secured). If password is checked, page will show you IP address of device selected by DHCP server in network. And now you are able to connect to conf-mode via your network and appropriate IP address.
</p>
<h3>IP address of the socket</h3>
<p>
User is able to set 10 IP addresses for each button. So one HTTP request will be send a maximum of 10 devices at once. You can add IP address via form where you also select with button should use this IP address. It is possible to delete each address.
</p>
<h3>JSON message</h3>
<p>
Behind button configure you can find feature to write JSON message to JSON API of socket. Current JSON is below the form.
</p>
<h3>Deep sleep button</h3>
<p>This button will put device to sleep. Holding both buttons during conf-mode has same effect.</p>
<h3>Disconnect button</h3>
<p>This button will disconnect device from WiFi.</p>

</body>
</html>

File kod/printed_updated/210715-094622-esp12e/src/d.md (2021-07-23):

<html>
<body>
<h1>NETIO button tutorial</h1>
<h2>Basic info</h2>
<p>
This is prototype of NETIO button that allow you to control the NETIO socket.
It works on sending HTTP request method.
On the other side, this communication is handled by the socket via JSON API. Button is made with small consumption. Button is only up when user sends HTTP request or turns on conf-mode.
</p>
<h3>Device structure</h3>
<p>
Device has 4 buttons.<br>
First button next to 5 programming pins is used for <b>programming.</b> <br>
Two buttons with S1 and S2 marks are used for <b>JSON configure</b>.
User can program those buttons via conf-mode. <br>
Last button is <b>RESET</b>. It is used for restart the device.<br>
</p>
<h3>LED and buzzer signaling</h3>
<p>
Device has LED with green and red color.
Buzzer is connected with red color of LED.<br>
If <b>green light</b> is on, device is trying to connect to wlan or communicate with the socket. <br>
If <b>red light</b> blinks once for longer time, device entered or quited conf-mode.<br> 
If <b>red light</b> blinks 2x with buzzer signalization, connection to wlan failed. <br>
If <b>red light</b> blinks 3x with buzzer signalization, HTTP communication failed.
Probably IP address of the socket is invalid. <br>
If <b>red light</b> blinks 4x with buzzer signalization, device wasn't able to recognize input. Please hold the button little bit longer.
</p>
<h2>Conf-mode</h2>
<p>
For entering conf-mode, hold both buttons until light turn on for 400ms. After that connect to AP called <b>NETIO-BUTTON</b>. Open browser and search <b>192.168.4.1</b>.
</p>
<h3>WiFi selection</h3>
<p>
On main screen, user is able to connect device to any close-range network without security or with WES, WPA or WPA2-personal. For update WiFi list, click on <b>Scan</b> button. <br>
By clicking on button with your wanted network, you will be transfer to security page (only if network is secured). If password is checked, page will show you IP address of device selected by DHCP server in network. And now you are able to connect to conf-mode via your network and appropriate IP address.
</p>
<h3>IP address of the socket</h3>
<p>
User is able to set 10 IP addresses for each button. So one HTTP request will be send a maximum of 10 devices at once. You can add IP address via form where you also select with button should use this IP address. It is possible to delete each address.
</p>
<h3>JSON message</h3>
<p>
Behind button configure you can find feature to write JSON message to JSON API of socket. Current JSON is below the form.
</p>

</body>
</html>

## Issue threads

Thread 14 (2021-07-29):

Přestavba desky

Escape96X, 2021-07-29:
Plošný spoj je třeba lehce upravit a přizpůsobit pro lepší nahrávání programu.

## Navrhované úpravy
- Přidat pin 3,3V pro napájení UARTU
- Přidat pin RESET pro připojení UARTU, konkrétně pin ESPEN
- Bzučák připojit na RED LED
- 3 AAA baterie místo 2AA

Escape96X, 2021-07-29:
# Aktuální plošňák
- Tyrkysová = rst
- Červená = 3,3V
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

Escape96X, 2021-08-02:
Volal jsem Břéťovi st. a zatím jsme se domluvili na těchto hodnotách. (V příloze je diagram aktuálního osazení desky)
Je to funkční.
Aktuálně osazuji desku na styl ENABLE BUTTON tzn. R8 připojené na katodu D2
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

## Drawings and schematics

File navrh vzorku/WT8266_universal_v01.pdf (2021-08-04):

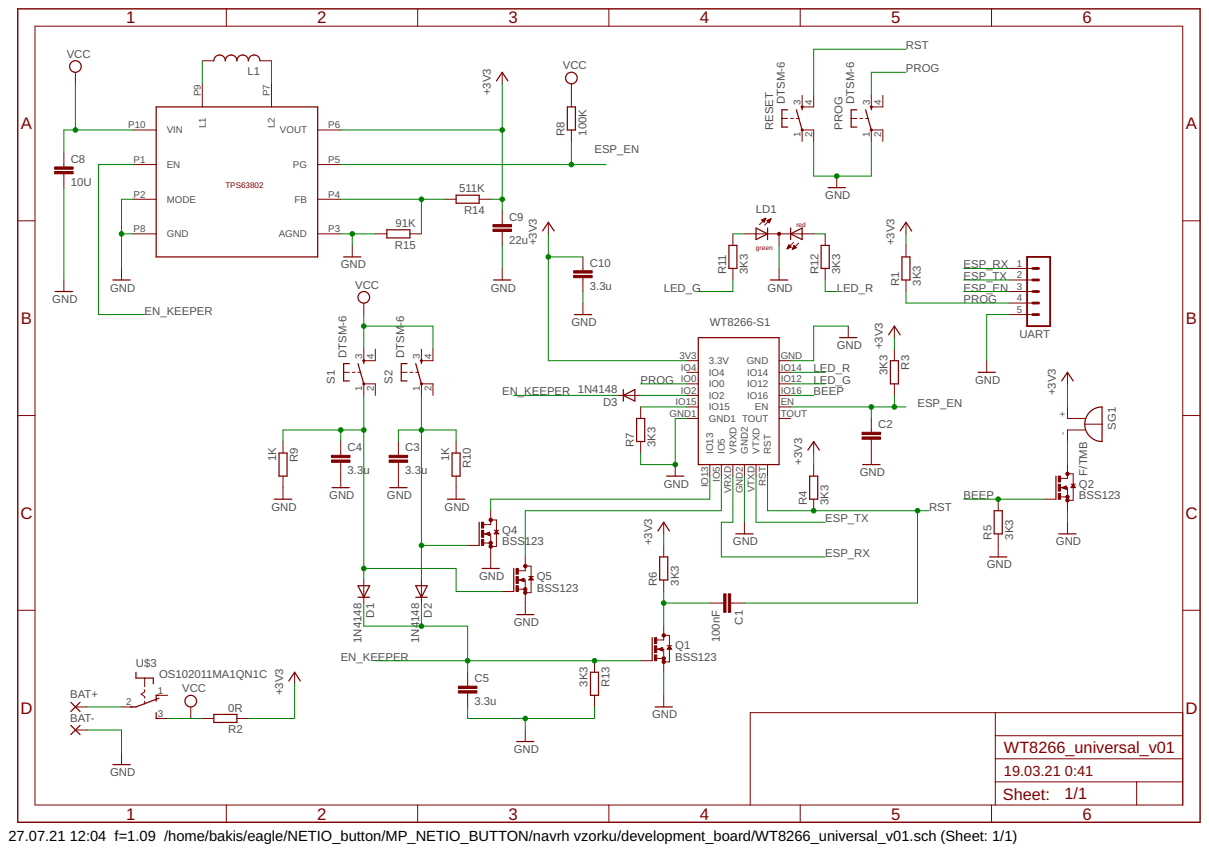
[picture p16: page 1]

27.07.21 12:04 f=1.09 /home/bakis/eagle/NETIO_button/MP_NETIO_BUTTON/navrh vzorku/development_board/WT8266_universal_v01.sch (Sheet: 1/1)

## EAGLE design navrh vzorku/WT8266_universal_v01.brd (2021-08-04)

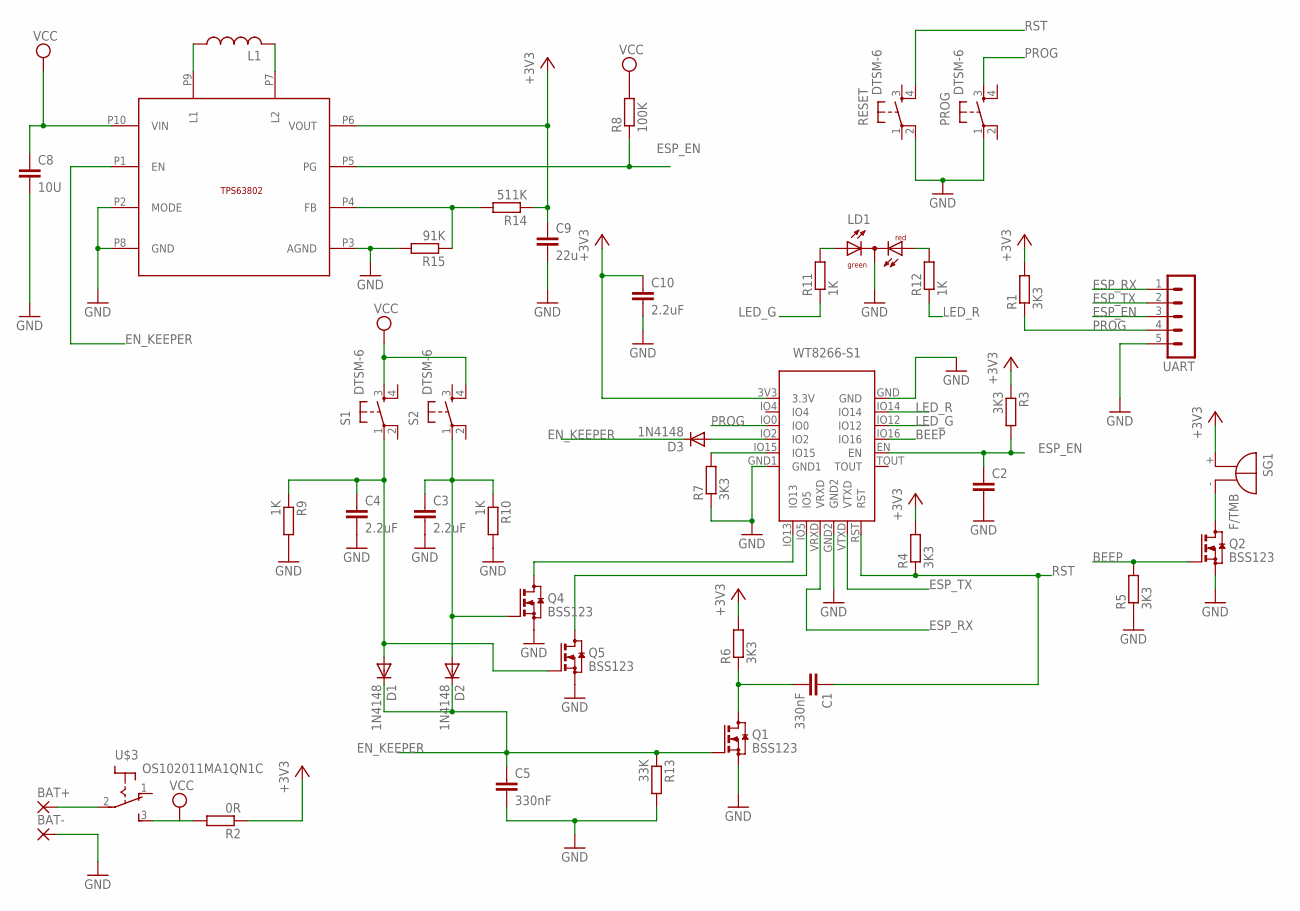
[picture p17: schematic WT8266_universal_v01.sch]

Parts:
BAT+: 2,54/1,0
BAT-: 2,54/1,0
C1, C5: 330nF; C0805
C2: C-EUC0805; C0805
C3, C4, C10: 2.2uF; C0805
C8: 10U; C0805
C9: 22u; C0805
D1, D2, D3: 1N4148; 0805
L1: L-USL2825P; L2825P
LD1: DUOLED-RG-C3MM; DUOLED-A-3MM
PROG: DTSM-6
Q1, Q2, Q4, Q5: BSS123; SOT23
R1, R3, R4, R5, R6, R7: 3K3; R0805
R2: 0R; R0805
R8: 100K; R0805
R9, R10, R11, R12: 1K; R0805
R13: 33K; R0805
R14: 511K; R0805
R15: 91K; R0805
RESET: DTSM-6
S1, S2: DTSM-6
SG1: F/TMB
U$1: WT8266-S1
U$3: OS102011MA1QN1C
U$4: TPS63802; VSON-HR-10
UART: MAR05-1

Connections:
+3V3: C9.1, C10.1, R1.2, R2.1, R3.1, R4.2, R6.2, R14.1, SG1.+, U$1.3V3 (3.3V), U$4.P6 (VOUT)
BEEP: Q2.1 (G), R5.2, U$1.IO16
EN_KEEPER: C5.1, D1.1 (C), D2.1 (C), D3.1 (C), Q1.1 (G), R13.1, U$4.P1 (EN)
ESP_EN: C2.1, R3.2, R8.1, U$1.EN, U$4.P5 (PG), UART.3
ESP_RX: U$1.VRXD, UART.1
ESP_TX: U$1.VTXD, UART.2
GND: BAT-.1, C2.2, C3.2, C4.2, C5.2, C8.2, C9.2, C10.2, LD1.2 (C), PROG.1, Q1.2 (S), Q2.2 (S), Q4.2 (S), Q5.2 (S), R5.1, R7.1, R9.2, R10.2, R13.2, R15.2, RESET.2, U$1.GND, U$1.GND1, U$1.GND2, U$4.P2 (MODE), U$4.P3 (AGND), U$4.P8 (GND), UART.5
LED_G: R11.1, U$1.IO12
LED_R: R12.1, U$1.IO14
unnamed: R14.2, R15.1, U$4.P4 (FB)
unnamed: C1.2, Q1.3 (D), R6.1
unnamed: R7.2, U$1.IO15
unnamed: D3.2 (A), U$1.IO2
unnamed: Q4.3 (D), U$1.IO13
unnamed: Q5.3 (D), U$1.IO5
unnamed: LD1.1 (AG), R11.2
unnamed: Q2.3 (D), SG1.-
unnamed: BAT+.1, U$3.2
unnamed: C3.1, D2.2 (A), Q4.1 (G), R10.1, S2.1
unnamed: L1.1, U$4.P9 (L1)
unnamed: C4.1, D1.2 (A), Q5.1 (G), R9.1, S1.1
unnamed: L1.2, U$4.P7 (L2)
unnamed: LD1.3 (AR), R12.2
PROG: PROG.3, R1.1, U$1.IO0, UART.4
RST: C1.1, R4.1, RESET.4, U$1.RST
VCC: C8.1, R2.2, R8.2, S1.3, S2.4, U$3.3 (S), U$4.P10 (VIN)

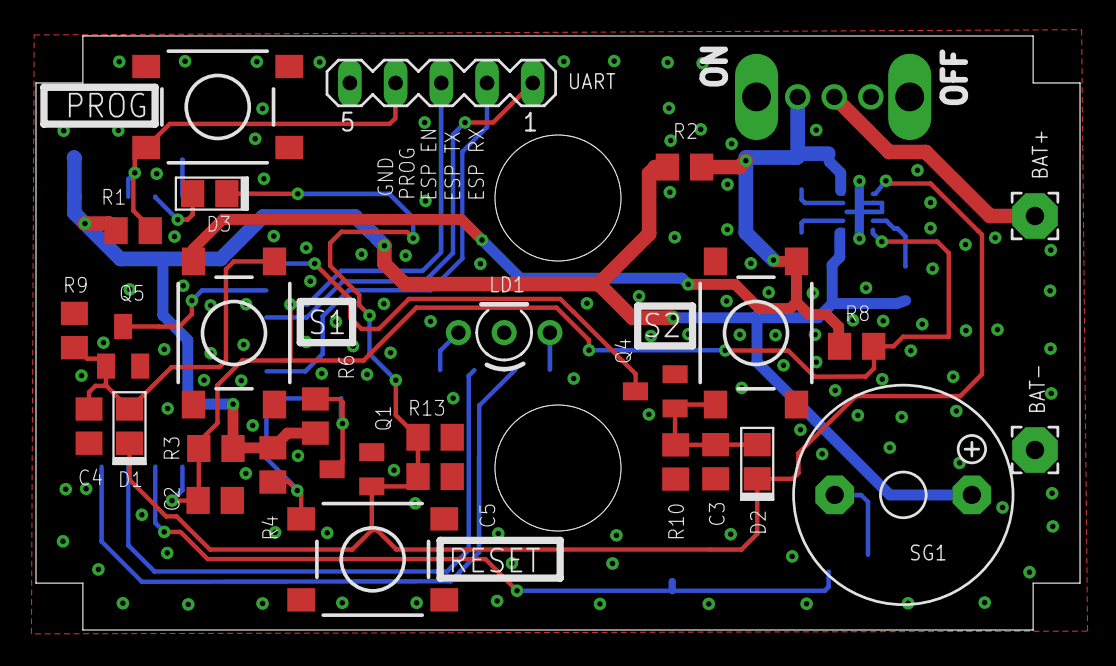
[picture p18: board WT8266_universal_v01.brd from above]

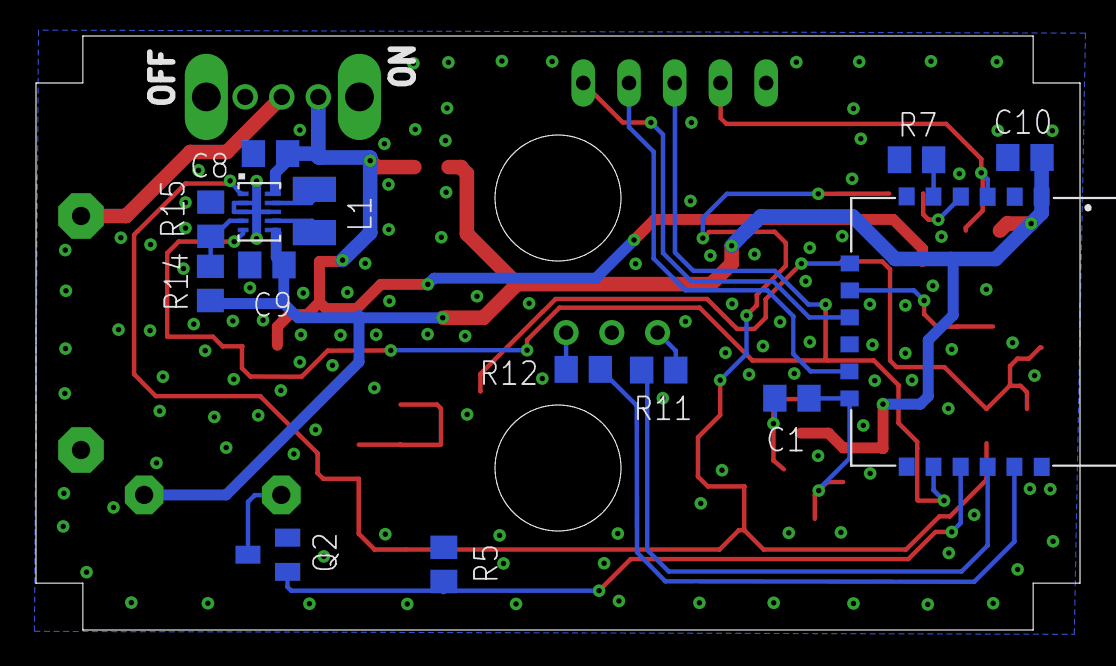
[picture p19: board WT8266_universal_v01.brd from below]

Board: 2 copper layers, 58.0 x 33.0 mm, 43 parts (14 on the bottom side), 26 nets.

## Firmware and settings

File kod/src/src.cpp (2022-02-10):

#include <EEPROM.h>
#include <ESP8266WiFi.h>
#include <ESP8266HTTPClient.h>
#include "header.h"
#include "define.h"


// konstanty-piny
const int WAKEUP_PIN1 = 5;
const int WAKEUP_PIN2 = 13;
// buzzer 14
const int BUZZER_PIN = 14;
const int LED_PIN = 12;
const int ENPin = 2;

// globalni promnene
bool BUTTONSTATE1 = false;
bool BUTTONSTATE2 = false;
bool errors = false;


WiFiClient wificlient;
HTTPClient http;

void feedback_timer(int duration, int quantity) {
    // feedback platformy
    for (int i = 0; i < quantity; i++) {
        digitalWrite(BUZZER_PIN, HIGH);
        delay(duration);
        digitalWrite(BUZZER_PIN, LOW);
        delay(100);
    }
}

bool pin_pressed() {
    // kontrola jake tlacitko bylo zmacknuto
    if (BUTTONSTATE1 == false) {
        return true;
    } else {
        return false;
    }
}

String http_post(String HTTP_CONNECTION, int position, bool button_pressed) {
    // posle http request zasuvce
    int offset = (button_pressed) ? HTTP_POSA : HTTP_POSB;
    if (http.begin(wificlient, HTTP_CONNECTION)) {
        Serial.println("zacal jsem http");
        int httpCode = http.POST(readContent(position, offset, HTTP_POSB, HTTP_JMP));
        if(httpCode > 0) {
            Serial.print("HTTP CODE: ");
            Serial.println(httpCode);
            Serial.print("pozice HTTP:");
            Serial.println(position);
            String payload = http.getString();
            Serial.println('payload');
            Serial.println(payload);

            if (payload.indexOf("Errors") > 0 || payload.length() == 0) {
                Serial.print("jsem v erroru");

                errors = true;
            }
            Serial.println(payload);
            http.end();
            return payload;
        } else {
            String payload = "HTTP failed with code: ";
            payload += httpCode;
            return payload;
        }
    }
    Serial.println("Kod je konec");
    return "Protocol failed";
}

String parsingIP(bool button_pressed) {
    // najde prislusnou ip adresu
    int offset = (button_pressed) ? IP_POSA : IP_POSB;
    int count = countContent(offset, IP_POSB, IP_JMP);
    // Serial.println(count);
    if (count == 0) {
        feedback_timer(200, 3);
        return "Table of actions is empty.";
    } else {
        String end_payload = "<table>";
        for (int i = 0; i < count; i++) {
            String HTTP_CONNECTION = "http://";
            String ip_address = readContent(i, offset, IP_POSB, IP_JMP);
            end_payload += "<th><td>"+ip_address + "</td><td>";

            HTTP_CONNECTION += ip_address;
            HTTP_CONNECTION += "/netio.json";
            end_payload += http_post(HTTP_CONNECTION, i, button_pressed);
            end_payload += "</td></th>";
            Serial.println(i);
            delay(200);
        }
        end_payload += "</table>";
        Serial.print("error:");
        Serial.println(errors);
        if (errors)
            feedback_timer(200, 3);
        return end_payload;
    }
}

void wifi_setup() {
    // precte z pameti ssid a password a pripoji se k wifi
    String ssid = readEEPROM(SSID_POS, SSID_LEN);
    String password = readEEPROM(PASSWORD_POS, PASSWORD_LEN);
    Serial.print("SSID and Password:");
    Serial.println(ssid);
    Serial.println(password);
    char *s = const_cast<char *>(ssid.c_str()); // prevede string na char*
    char *p = const_cast<char *>(password.c_str());
    delay(300);
    if (WiFi.status() != WL_CONNECTED) {
        WiFi.begin(s, p);
        for (int i = 0; i < 50; i++) { // kontroluje zda bylo pripojeno k wifi, po 5s se vypne esp
            if (WiFi.status() == WL_CONNECTED)
                break;
            delay(100);
            Serial.print(".");
        }
        Serial.println(' ');
        if (WiFi.status() != WL_CONNECTED) {// pokud neni pripojen ohlasi chybu
            feedback_timer(200, 2);
            Serial.print("WiFi status: ");
            Serial.println(WiFi.status());
            WiFi.disconnect();
            ESPSleep();
        }
    }
}

bool check_conf_mode() {
    // overi zda jsou oba piny zmackle pro konfiguracni mod
    if (!BUTTONSTATE1 && !BUTTONSTATE2) {
        feedback_timer(400, 1);
        Serial.println("Config mode enabled");
        setWiFiServer2();
        return true;
    } else if (BUTTONSTATE1 && BUTTONSTATE2) {
        feedback_timer(200, 4);
        ESPSleep();
        return false;
    } else
        return false;
}


void send_message() {
    wifi_setup();
    parsingIP(pin_pressed());
}

void setup_boot() {
    // nastaveni po startu
    pinMode(ENPin, OUTPUT);
    digitalWrite(ENPin, HIGH);
    pinMode(WAKEUP_PIN1, INPUT_PULLUP);
    pinMode(WAKEUP_PIN2, INPUT_PULLUP);
    BUTTONSTATE1 = digitalRead(WAKEUP_PIN1);
    BUTTONSTATE2 = digitalRead(WAKEUP_PIN2);
    Serial.begin(115200);
    EEPROM.begin(4096);
    pinMode(BUZZER_PIN, OUTPUT);
    pinMode(LED_PIN, OUTPUT);
    Serial.println("Načtení pinu");
}

void ESPSleep() {
    digitalWrite(ENPin, LOW);
}

void debug() {
    //debug zpravy z pameti
    Serial.println("WiFi login");
    Serial.println(readEEPROM(SSID_POS, SSID_LEN));
    Serial.println(readEEPROM(PASSWORD_POS, 64));
    Serial.println("Button state detection:");
    Serial.print("Button S1:");
    Serial.println(BUTTONSTATE1);
    Serial.print("Button S2:");
    Serial.println(BUTTONSTATE2);
    Serial.println("");
    //debugPair();
}

void setup() {
    setup_boot();
    debug();
    if (!check_conf_mode()) {
        digitalWrite(LED_PIN, HIGH);
        Serial.println("Standard mode enabled");
        send_message();
        ESPSleep();

    }
}

void loop() {
    delay(1);
    handleServer();
    if (!digitalRead(WAKEUP_PIN1) && !digitalRead(WAKEUP_PIN2)) {
        feedback_timer(400, 1);
        ESPSleep();
    }

}

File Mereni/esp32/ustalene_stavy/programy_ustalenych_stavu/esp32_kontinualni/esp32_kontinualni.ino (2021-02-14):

const int button = 17;
int buttonState = 0;


void setup() {
  Serial.begin(115200);
   pinMode(button, INPUT);

}

void loop() {
   buttonState = digitalRead(button); // cteni stavu tlacitka
   delay(100);
   Serial.println("Probiha");
  if (buttonState == HIGH)
  {
    Serial.println("Tlacitko bylo zmacknuto");
  }

}

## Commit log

2020-09-22 Pridano zadani a button-ESP8266.ino a button-ESP32
2020-10-27 Schéma UART a enable
2020-12-15 Redukce board
2021-01-26 dokumentace - Měření spotřeby operací
    [Výsledky měření.xlsx]
2021-01-29 ESP32 CODE
2021-01-29 ESP32 CODE1
2021-02-04 ESP8266 DEEP SLEEP TEORIE
    [Výsledky měření - ESP32.xlsx, Výsledky měření.xlsx]
2021-02-12 ESP32 měřené
    [Výsledky měření.xlsx]
2021-02-14 Zapsání výsledků měření
    [Výsledky měření - ESP32.xlsx, Výsledky měření.xlsx]
2021-02-22 EAGLE vzorek
    [ESP32.sch, Výsledky měření - ESP32.xlsx, Výsledky měření.xlsx]
2021-02-28 Funkcni vzorky eagle
    [ESP32.sch, esp8266.sch]
2021-03-04 Program funčního vzorku ESP
    [ESP32.brd, ESP32.sch]
2021-03-07 funkcni vzorek ESP8266
    [ESP32.brd, ESP32.sch, esp8266.brd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]
2021-03-08 Dokumetace tvorba esp8266 vzorku
    [ESP32.brd, esp8266.brd]
2021-03-10 Plosne spoje
    [ESP32-velky stabilizator.brd, ESP32-velky stabilizator.sch, ESP32.brd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]
2021-03-14 LATEX DOKUMENTACE
    [ESP32-velky stabilizator.brd, ESP32-velky stabilizator.sch, ESP32.brd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]
2021-03-29 SOC soutez
    [ESP32.brd, ESP32.sch, Výsledky měření - ESP32.xlsx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]
2021-04-10 Finalni verze
    [ESP32.brd, ESP32.sch, Výsledky měření - ESP32.xlsx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]
2021-07-28 HTTP table
    [partitions_custom.csv]
2021-07-29 New menu
    [WT8266_universal_v01.brd, WT8266_universal_v01.sch]
